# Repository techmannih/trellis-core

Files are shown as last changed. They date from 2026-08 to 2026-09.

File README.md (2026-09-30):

# Trellis Core

A compact, four-layer Linux board built around the Allwinner T113-S3 application processor.

## Overview

Trellis Core combines the processor, managed flash, power supplies, clocks, USB-C interface, boot controls, display expansion, debug UART, and a programmable status LED required for a small Linux-capable system. The complete schematic, component placement, connectivity, and autorouter configuration are written in TypeScript and JSX, making the board easy to inspect and modify as code.

## Hardware

| Block | Implementation |
| --- | --- |
| Processor | Allwinner T113-S3 application processor |
| Power input | 5 V through USB-C with resettable-fuse protection |
| Main rails | 3.3 V system rail and sequenced 0.9 V core rail |
| Auxiliary rails | 1.8 V and 1.5 V generated by the processor's internal regulators |
| Storage | ZDSD04GLGEAG 4 Gbit (512 MB) SD NAND on the four-bit SDC0 interface |
| USB | USB 2.0 data with ESD protection and USB-C configuration resistors |
| Clocks | 24 MHz main crystal and 32.768 kHz low-frequency crystal |
| Display expansion | SPI1 on a six-pin, 1 mm-pitch JST-SH connector |
| Debug | UART0 on a four-pin, 1 mm-pitch JST-SH connector |
| Status | 5 V XL-2121 addressable RGB LED driven through a 3.3 V-to-5 V AHCT buffer |
| Controls | Processor reset, boot selection, board identification, and flash clock control |
| PCB | 50 mm × 50 mm, four layers with an inner GND plane, 1.6 mm thick, four 2.7 mm mounting holes |
| Assembly | All components on the top side |
| Routing | Four-layer autorouting with `5x` effort, 0.15 mm minimum / 0.2 mm nominal traces, and 0.3 mm via holes with 0.45 mm pads |

## How it works

```mermaid
flowchart LR
  USB[USB-C connector] -->|5 V| FUSE[Resettable fuse]
  FUSE --> VBUS[Protected VBUS]
  VBUS --> BUCK33[3.3 V buck regulator]
  VBUS --> BUCK09[0.9 V buck regulator]
  BUCK33 -->|3.3 V| CPU[T113-S3 processor]
  BUCK33 -->|3.3 V| FLASH[Managed flash]
  BUCK33 -->|Power-good enables| BUCK09
  BUCK09 -->|0.9 V core| CPU
  USB <-->|D+ / D- through ESD protection| CPU
  CPU <-->|SDC0 data and command| FLASH
  CPU -->|SPI1| DISPLAY[6-pin JST-SH display connector]
  CPU <-->|UART0| DEBUG[4-pin JST-SH debug connector]
  CPU --> RGB[Addressable RGB status LED]
  CLOCKS[24 MHz and 32.768 kHz clocks] --> CPU
  CONTROLS[Reset and boot controls] --> CPU
  CONTROLS --> GATE[Flash clock gate]
  CPU --> GATE --> FLASH
```

1. The USB-C connector supplies 5 V power and USB 2.0 data. A resettable fuse protects the power path, while an ESD protection device sits between the connector and the processor's USB pins.
2. The first buck regulator creates the 3.3 V system rail. Its power-good output enables the second regulator so the 0.9 V processor core rail starts in sequence.
3. The processor uses its internal regulators for the 1.8 V and 1.5 V auxiliary rails. Local capacitors provide decoupling for every power domain.
4. The 24 MHz crystal provides the main clock and the 32.768 kHz crystal provides the low-frequency clock used by the processor.
5. Managed flash connects to the processor over the four-bit SDC0 bus. A logic gate, pull-ups, and a pushbutton network control the storage clock during boot and recovery.
6. SPI1 is broken out for a display, UART0 is available for a 3.3 V serial console, and the LEDC-capable PE5 pin drives the addressable RGB LED through U8 (SN74AHCT1G125) and a 33 Ω series resistor. U8 and the LED use protected VBUS; R27 holds the buffer input low during reset.
7. Reset, boot-selection, and board-identification resistor networks define the startup state. After placement, tscircuit autoroutes the board across all four copper layers.

## Expansion connectors

Both expansion connectors are JST-SH, 1 mm pitch. Pin numbering below follows the schematic and footprint definitions.

| J2 pin | SPI1 display signal | T113-S3 pin |
| --- | --- | --- |
| 1 | P3V3 | — |
| 2 | GND | — |
| 3 | SPI1_CLK | PD11 |
| 4 | SPI1_MOSI | PD12 |
| 5 | SPI1_MISO | PD13 |
| 6 | SPI1_CS0 | PD10 |

| J3 pin | UART0 debug signal | T113-S3 pin |
| --- | --- | --- |
| 1 | P3V3 | — |
| 2 | GND | — |
| 3 | UART0_TX | PE2 |
| 4 | UART0_RX | PE3 |

J3 uses 3.3 V logic. Use a 3.3 V USB-to-UART adapter, connect adapter RX to J3 TX and adapter TX to J3 RX, and do not apply 5 V to any J3 signal or power pin.

## How to program the board

Before applying power, follow [first-board power and firmware checks](docs/bring-up.md).
J1 is a 5 V input with passive CC pull-downs; it has no USB-PD negotiation or
source-current detection. Startup/steady current and USB source compatibility
must be measured on the prototype.

The board is programmed through its existing USB-C data connector using the T113-S3 BootROM's USB FEL mode. No separate programmer IC is fitted or required for this flow. SW2 disables the managed-flash clock so the installed image can be bypassed during recovery, and SW1 resets the processor. The boot behavior and peripheral pin functions are documented in the [T113-S3 user manual](https://turl.linux-sunxi.org/T113-S3/T113-S3_User_manual_v1.1_20210830.pdf) and [datasheet](https://dl.linux-sunxi.org/T113-S3/T113-S3_Datasheet_v1.6_20220303.pdf).

### Programming theory

Every time the processor is reset, it starts by executing an immutable first-stage program from its internal BootROM. Under normal conditions, the `SD_FLASH_CLK_GATE_EN` pull-up enables U6, allowing the SDC0 clock to reach the managed flash so the BootROM can load the installed boot image.

R12/R13 pull BOOT_SEL1/0 high. In GPIO boot-select mode, `11` tries SMHC0 first (T113-S3 user manual, Table 3-7), matching the SD NAND connection. This assumes the CPU has not been configured for an overriding eFuse boot policy.

Holding SW2 pulls `SD_FLASH_CLK_GATE_EN` low. U6 then blocks the storage clock, preventing the managed flash from responding during the next boot. After SW1 resets the processor, the BootROM cannot boot the stored image and exposes its FEL recovery interface over the USB data lines connected to J1. The host-side XFEL tool communicates directly with this BootROM interface, which is why an additional programmer IC is unnecessary.

FEL initially provides only a small recovery environment. XFEL first loads the T113-S3 DDR initialization code and can then upload a temporary loader, recovery U-Boot, or flashing image into RAM. That temporary program writes the final bootloader and system image to managed flash. Release SW2 once FEL is detected, before the RAM loader accesses storage. This restores the storage clock without resetting the CPU; resetting after a successful write starts the newly programmed image. J3 UART0 is optional and is used for boot logs and debugging, not for transferring the firmware image.

### Programming procedure

Identify the buttons by their component references:

| Button | Function | When to use it |
| --- | --- | --- |
| **SW1 — RESET** | Resets the T113-S3 processor | Press and release while holding SW2 to start recovery, or after programming to reboot. |
| **SW2 — FEL / SD FLASH DISABLE** | Blocks the SD NAND clock while held | Hold during power-on/reset to bypass storage boot; release after FEL detection, before accessing storage. |

1. Optionally connect J3 GND/TX/RX to a 3.3 V USB-to-UART adapter. Leave the adapter's power pin disconnected when USB-C powers the board.
2. Hold **SW2 (FEL)**, connect a USB-C **data** cable to the host, then press and release **SW1 (RESET)** while continuing to hold SW2. This powers and resets the CPU with the SD NAND clock blocked.
3. Run `xfel version` and confirm FEL detection. **Release SW2 (FEL) now**, without resetting, so a RAM loader can access the SD NAND.
4. Run `xfel ddr t113-s3`, then load a T113-S3 recovery image that supports this board's SDC0 pinout and SD NAND. No tested recovery image or partition layout is included in this repository.
5. Use that image's SD/MMC storage-writing procedure, verify the write, and reset with **SW1 (RESET)**. XFEL's `spinand` commands target SPI NAND and do not program this SDC0-attached part.

This is the intended hardware recovery path, verified against the netlist and component documentation. FEL entry, DDR initialization, and storage writes still need testing on a physical board with a compatible recovery image.

See the [XFEL quick start](https://xfel.xboot.org/en/guide/getting-started/) for host setup and RAM-loading examples; its [T113 implementation](https://github.com/xboot/xfel/blob/master/chips/r528_t113.c) provides the `t113-s3` DDR profile. Storage write offsets are image-specific and should not be guessed.

## RGB control

U7 is powered by protected 5 V VBUS. Its [manufacturer datasheet](https://www.lcsc.com/datasheet/C5349957.pdf) specifies full operation at 4.5–5.5 V and a DIN high threshold of 0.65 × VDD. U8's [TTL-compatible input](https://www.ti.com/lit/ds/symlink/sn74ahct1g125.pdf) accepts the CPU's 3.3 V output and drives DIN at the LED supply voltage. C45 and C46 bypass the LED and buffer separately. Configure PE5 for LEDC-DO and use the LED's single-wire protocol; WLED firmware is not included.

## Fabrication and assembly

Use [fabrication and assembly notes](docs/assembly.md) with the BOM and placement
files. D1 has a printed cathode `K` and anode/cathode fabrication labels. U5 and
U7 have 0.18 mm-stroke pin-1 circles and fabrication callouts. U5 retains its
1.27 mm solder-land spacing; the notes document coverage of the Zetta package's
1.25 mm-pitch terminals and the nominal 0.1575 mm minimum side margin.
The board uses 0.30 mm via holes and 0.45 mm
outer copper diameters; select the corresponding fabrication option.

`bun run check:assembly` checks U5 terminal coverage, the presence of polarity
notes, and the position, stroke and pad clearance of the pin-1 markers. It is
part of `bun run verify`. After verification, `bun run export:assembly` creates
`dist/index/assembly-top.svg`, showing pads, pin numbers, silk and fabrication
notes without routed copper. Send that drawing and `docs/assembly.md` to the
assembler and inspect the actual placement preview before manufacturing.

## Decoupling and review checks

The board selects `autorouterVersion="beta_pipeline7"` to preserve its explicit bypass, crystal, and LED signal paths as fixed copper. With the pinned tscircuit version, Pipeline 9 can move these paths and introduce vias despite `maxViaCount={0}`. Via-to-pad clearance is explicitly set to 0.1 mm so routing and final DRC use the same limit. The Y1–C33 load-capacitor branch also has an explicit zero-via route.

The 0.45 mm via pads are used throughout, including the manual ground vias. Routing uses a 0.15 mm minimum trace width; the C21 and LXIN escape corners are staggered to maintain clearance at that width.

No dependency patch is applied. `scripts/via-net-identity.test.mjs` uses the real autorouter to route GND and SIGNAL on inner1, then checks that each copper route reaches both intended through-vias and stays separate from the other net. The vias themselves must remain connected to their declared source nets. It does not require a particular source trace ID or replace the board's copper-short check. The missing route-attribution case is reproduced in [core #4002](https://github.com/tscircuit/core/pull/4002), and the same-GND short reports are covered by [check-shorts #62](https://github.com/tscircuit/check-shorts/pull/62) and addressed upstream by [fix #65](https://github.com/tscircuit/check-shorts/pull/65).

The [decoupling map](scripts/decoupling-map.json) lists every local bypass capacitor, its exact IC power/reference pin, and its maximum routed length. Each `DECOUPLE_C*` trace has a dedicated physical path. All components are assembled on the top side. Every bypass path stays on top with no vias and a 3 mm ceiling; adjacent CPU power pins fan out to spaced capacitor rows around the package. Capacitor pin 1 faces the IC. Each pin 2 has a dedicated return of at most 1 mm to a nearby through-via tied to the inner GND plane. `decouplingFor` remains on each capacitor for inspection; an explicit trace supplies the physical route, so `decouplingTo` is intentionally omitted to avoid duplicate generated traces.

`bun run check:decoupling` measures the built copper polyline, including both sides of vias and via depth. It fails for missing/wrong pin mappings, missing direct routes, ungrounded capacitors, changed limits, excessive length, bottom-side components, bypass layer changes, or any build errors. It is part of `bun run verify`. These are board layout constraints, not a substitute for power-integrity measurements.

The remaining capacitors have different roles: C3/C5/C6 are regulator output reservoirs; C10/C22/C29 are rail bulk storage; C2/C4 are feedback feed-forward capacitors; C8 is the power-good filter; C32/C33/C36/C37 are crystal loads; C40 is the reset filter; C44 filters the flash-clock enable. They are not counted as local IC bypasses.

The schematic uses power-marked rails, a standard USB-C connector symbol, and crystal symbols for Y1/Y2. Signal nets with voltage text in their names are explicitly classified to keep their labels correct. Net labels and power/ground symbols are generated automatically; this project does not use manual `<netlabel>` elements. The expansion sheet groups the populated SPI/UART connectors, boot straps, and RGB circuitry; CPU power and bypasses remain together on CPU Core.

## Uses

- A starting point for compact Linux-based controllers and USB-connected embedded devices
- A reference design for T113-S3 power sequencing, clocking, storage, and USB integration
- An example of describing a dense processor board entirely in tscircuit and TypeScript
- A test project for PCB placement, autorouting, 3D rendering, and manufacturing-export workflows
- A base design with SPI display and UART debug expansion for application-specific firmware

The current board focuses on the processor core, power, USB, storage, a compact SPI display bus, and serial debug. Additional product-specific I/O may still be needed before using it as a complete end product.

## Getting started

Install [Bun](https://bun.sh/), then run:

```sh
bun install
bun run dev
```

`bun run dev` opens the interactive tscircuit viewer, where the schematic, PCB, and 3D assembly can be inspected.

## Commands

| Command | Purpose |
| --- | --- |
| `bun run dev` | Open the interactive tscircuit viewer |
| `bun run typecheck` | Check the TypeScript source |
| `bun run verify` | Run netlist, placement, build, actual decoupling length, and copper-short checks |
| `bun run check:decoupling` | Check local bypass routes in the existing build |
| `bun run check:assembly` | Check flash terminal coverage, polarity notes and orientation markers |
| `bun run export:assembly` | Generate the top-side assembly drawing from the verified build |
| `bun run build` | Generate circuit JSON under `dist/` |
| `bun run build:preview` | Generate PCB, schematic, and 3D preview images |
| `bun run build:handoff` | Generate KiCad, STEP, and GLB handoff files |
| `bun run snapshot:update` | Refresh checked PCB and schematic snapshots |
| `bun run snapshot:3d:update` | Refresh the checked 3D snapshot |

## Generated outputs

Build artifacts are written under `dist/`:

- `dist/index/circuit.json` contains the complete generated circuit
- Preview builds add PCB, schematic, and 3D images
- Handoff builds add a KiCad project archive, STEP model, and GLB models

## Project structure

```text
.
├── index.circuit.tsx      Board definition, connectivity, and placement
├── imports/               Component wrappers, footprints, and CAD models
├── __snapshots__/         Checked PCB, schematic, and 3D renders
├── tscircuit.config.json  Project entrypoint and build configuration
├── tsconfig.json          TypeScript configuration
└── package.json           Development, verification, and export commands
```

## Current status

Run `bun run verify` to reproduce the electrical, placement, routed decoupling, and copper-short checks. Checked schematic, PCB, and 3D views are stored in `__snapshots__/`.

Hardware bring-up and a compatible recovery/flashing image remain unverified.
Use [the bring-up procedure and results record](docs/bring-up.md) to capture
current/rail measurements, FEL, DDR, storage and boot evidence. Inspect the
generated handoff files and run fabrication-specific DRC before manufacturing.

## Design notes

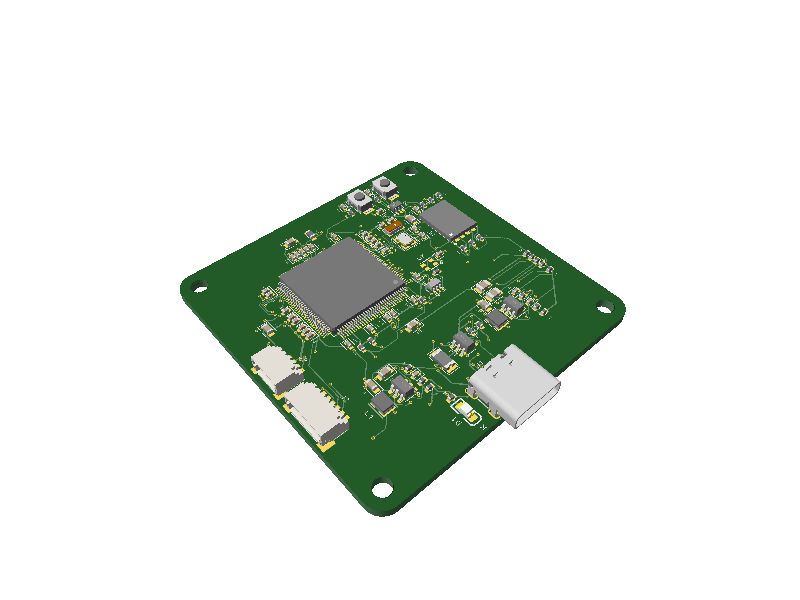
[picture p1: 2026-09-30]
__snapshots__/index.circuit-3d.snap.png

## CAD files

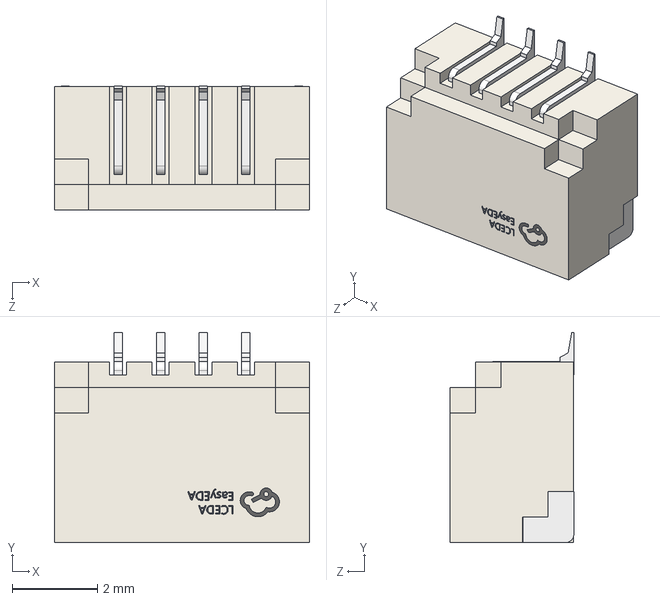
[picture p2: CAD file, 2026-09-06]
imports/SM04B_SRSS_TB_LF__SN_/SM04B_SRSS_TB_LF__SN_.step
6.00 x 4.95 x 2.91 mm

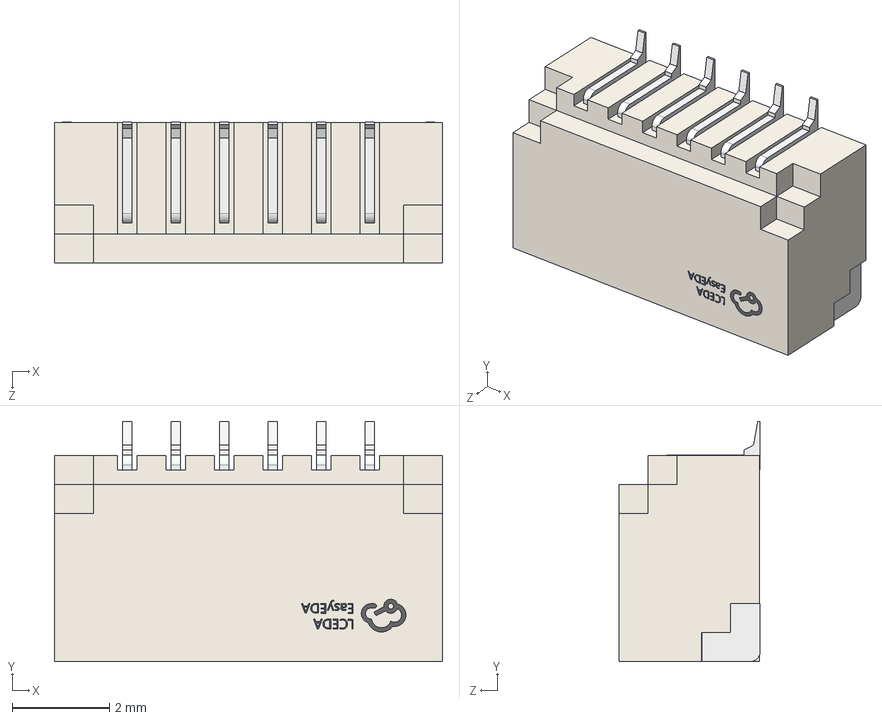
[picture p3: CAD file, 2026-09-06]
imports/SM06B_SRSS_TB_LF__SN_/SM06B_SRSS_TB_LF__SN_.step
8.00 x 4.95 x 2.91 mm

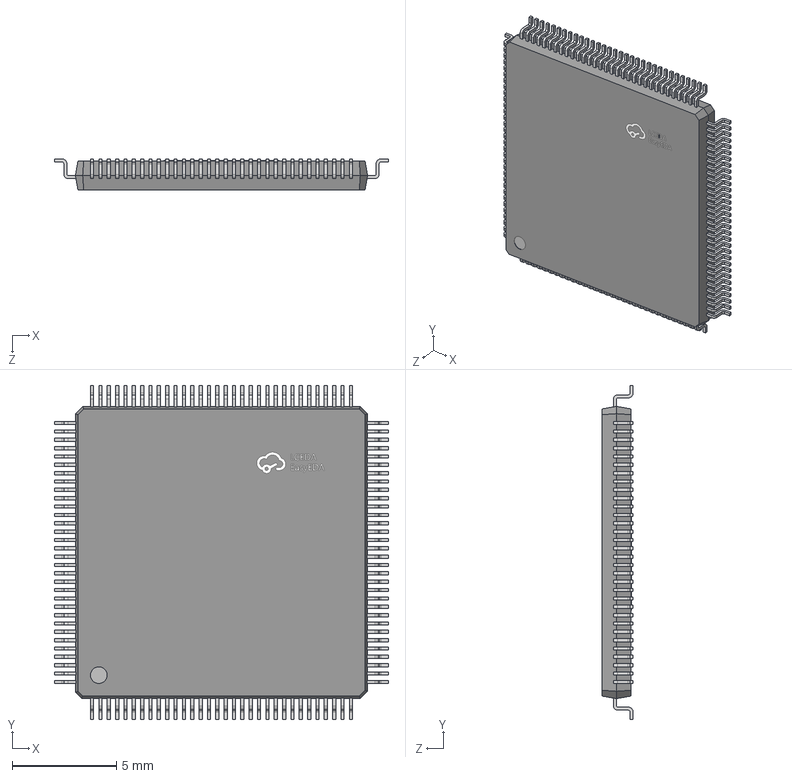
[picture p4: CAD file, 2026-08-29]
imports/T113_S3/T113_S3.step
16.0 x 16.0 x 1.50 mm

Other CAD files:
imports/SM04B_SRSS_TB_LF__SN_/SM04B_SRSS_TB_LF__SN_.obj
imports/SM06B_SRSS_TB_LF__SN_/SM06B_SRSS_TB_LF__SN_.obj
imports/T113_S3/T113_S3.obj

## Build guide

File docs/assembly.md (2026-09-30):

# Fabrication and assembly notes

Applies to the Trellis Core layout in this repository. View the board from the
component/top side with USB-C J1 at the bottom. All components are top-side.

## Files to supply with the order

Run `bun run verify`, then `bun run export:assembly`. Supply the resulting
`dist/index/assembly-top.svg` and this document with the BOM, component placement
file and final fabrication outputs. The assembly drawing is a top view, not a
mirrored bottom view. Fabrication notes belong in the assembly/F.Fab documentation;
they are not extra copper or extra silkscreen text.

Confirm that the assembler's placement preview aligns the physical package marks
with the pad functions below. A placement-file rotation number alone is
insufficient because library zero-angle conventions can differ.

## Orientation of the polarized parts

| Reference | Part | Orientation on this board |
| --- | --- | --- |
| D1 | NCD0805R1 | Pin 2/anode is the upper pad, connected to P3V3. Pin 1/cathode is the lower pad, connected through R4 to GND. The printed `K` identifies the cathode end; assembly labels are `A (+)` and `K (-)`. |
| U5 | ZDSD04GLGEAG | Pin 1/DAT2 is the leftmost pad in the lower row. Align the package pin-1 corner with the PCB circle and `1 DAT2` callout. U5 is placed at 90 degrees in the source layout. |
| U7 | XL-2121RGBC-2812B | The package's marked/chamfered corner is pin 1/DIN, at the lower-right corner on this board. Align it with the PCB circle and `1 DIN` callout. |

U7 top view:

```text
       3 / DO       2 / VDD (+5 V)
           +-------+
           |  U7   |
           +------/  <- package mark
       4 / GND      1 / DIN   o <- PCB dot
```

Pin 3/DO is intentionally unconnected. Do not use a generic WS2812 package pinout
to override the drawing for this exact XINGLIGHT part.

U5 top view in its current board rotation:

```text
   8 VDD     7 DAT1     6 DAT0     5 CMD
        +-----------------------+
        |          U5           |
        +-----------------------+
   1 DAT2    2 DAT3     3 CLK      4 GND
 o <- PCB pin-1 circle
```

### U5 package pitch and solder lands

The Zetta package has **1.25 mm terminal pitch**. The existing PCB solder lands
retain **1.27 mm spacing**, with centers at +/-1.905 and +/-0.635 mm in each
unrotated column. These are different dimensions: the wider solder lands can
accommodate the package terminals. With a centered package, the largest terminal
center offset is 0.030 mm. The 0.800 mm land width along the pitch direction and
datasheet maximum terminal width `b = 0.425 mm` leave a minimum nominal side
margin of `(0.800 - 0.425) / 2 - 0.030 = 0.1575 mm`.

This land pattern preserves the verified copper routing. The geometry check
requires at least 0.15 mm nominal side margin; it does not establish assembly
placement/process tolerances. Ask the assembler to confirm this exact LGA8 land
pattern against the package drawing during DFM. Do not substitute a generic
1.27 mm-pitch IC for U5.

U5 and U7 orientation circles use 0.18 mm strokes; D1's cathode character is
1 mm high.

The remaining ICs must also match their pin-1 marks and the placement preview.
J2/J3 pin 1 is P3V3 and pin 2 is GND; connector pinouts are in the README. All
populated capacitors are ceramic/MLCC parts and do not require +/- polarity.

## PCB fabrication settings

| Item | Design value |
| --- | --- |
| Size | 50 x 50 mm |
| Copper layers | 4; inner1 is GND |
| Nominal thickness | 1.6 mm |
| Via hole / outer copper diameter | 0.30 / 0.45 mm |
| Via radial annular ring | 0.075 mm |
| Trace width | 0.15 mm minimum; 0.20 mm nominal |
| Mounting holes | Four 2.7 mm NPTH holes |

Select the **0.30 mm minimum via-hole option**. Do not allow the drill size to be
enlarged automatically without checking the copper ring and all clearances.
Confirm support and pricing for 0.30/0.45 mm vias in the fabrication quote.
If changing outer diameters for cost, rerun routing
and clearance checks. The chosen copper weight, stackup, mask treatment and
surface finish must be reflected in the actual manufacturing order.

Before release, inspect the generated Gerber/drill files and placement preview,
including pin-1 marks, mask openings and the manufacturer's DFM results. The
repository's checks do not replace that review.

## Reference drawings

- [Zetta ZDSD04GLGEAG manufacturer datasheet](https://www.lcsc.com/datasheet/C2875854.pdf): revision 1.3, printed pages 4 and 16, top-view pin assignment and LGA8 dimensions (`e = 1.25 BSC`).
- [XINGLIGHT XL-2121RGBC-2812B manufacturer datasheet](https://www.lcsc.com/datasheet/C5349957.pdf): printed page 11, marked corner, top-view DI/VDD/DO/GND arrangement and pin table.
- [JLCPCB rigid PCB capabilities](https://jlcpcb.com/capabilities/pcb-capabilities): via/drill and legend dimensions, checked 15 September 2026. Recheck the selected process at order time.

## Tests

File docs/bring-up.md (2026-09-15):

# First-board power and firmware test

Status: **not yet tested on physical hardware**. This procedure makes the open
checks reproducible; it is not a record of a successful boot.

## Power-input contract

J1 accepts **5 V**. Its CC1 and CC2 each have a 5.1 kohm pull-down. The board has
no USB-PD controller or CC current-advertisement detector. It therefore does not
negotiate a higher voltage or determine whether a Type-C source advertises
1.5 A/3 A. Do not assume either current is available from every USB port.

For bench evaluation, use a known regulated 5 V source with at least 1 A capacity
and adjustable current limiting, through a suitable USB power fixture. Source
capacity is test headroom, not measured board demand or permission to exceed a
USB port's advertised allowance. F1 is a resettable fuse, not a USB current
negotiator or precise current limiter. Record startup peaks as well as steady
current, including any load on J2/J3.

For FEL/data tests, choose a host/hub or powered test fixture that supports both
USB data and the measured demand. If using separate bench power while connected
to a host, use a fixture that isolates the host's VBUS; do not directly parallel
two 5 V sources. When J1 powers the board, leave the UART adapter's power pin
disconnected and connect only GND/TX/RX at 3.3 V logic levels.

If measured demand exceeds the applicable default USB allowance, resolve the
power architecture before qualifying general USB operation: reduce demand or
add appropriate source-current detection/current control. Add PD negotiation if
the intended product requires a PD contract. An arbitrary larger supply does not
close this compatibility check.

## Test order

1. **Unpowered inspection:** compare D1/U5/U7 marks against [assembly.md](assembly.md),
   inspect solder joints and check for sustained low-resistance shorts between
   VBUS/power rails and GND. Allow capacitors to charge during resistance checks.
2. **Initial power:** with RESET held, apply 5.0 V with a conservative initial
   current limit (for example 100 mA for a short-check stage). Record whether the
   supply limits. This low-limit stage is not a boot test; investigate a sustained
   limit before increasing it. Stop and inspect if a component heats unexpectedly.
3. **Rail checks:** measure protected VBUS and nominal 3.3 V, 0.9 V, 1.8 V and
   1.5 V at accessible capacitor pads. Record results; compare measured limits to
   the regulator/processor datasheets. Use a scope to confirm that 3.3 V precedes
   the 0.9 V rail and to inspect startup/reset behavior. Check the drop across F1.
4. **Startup current:** establish a justified current limit within the source,
   connector and board limits, release RESET and record peak and steady current.
   A current-limited brownout is not evidence by itself of a bad PCB.
5. **FEL:** follow the README's SW2/SW1 sequence using a USB data connection.
   Record `xfel version` output. Release SW2 after FEL detection before accessing
   the SD NAND clocked through U6.
6. **DDR and storage:** record `xfel ddr t113-s3` output. Use a compatible RAM
   recovery image with this board's SDC0 pinout and managed SD NAND support.
   Record the exact image revision/checksum and its partition/write procedure.
   Do not substitute XFEL's SPI-NAND write commands for this SD/MMC device.
7. **Boot verification:** verify the storage write/readback, reset, collect UART
   logs, and repeat a cold boot. Then check the RGB LED and any expansion load,
   repeating the current measurement under that load.

No tested recovery image or partition layout is shipped here. Storage write
offsets are image-specific; physical testing and a compatible image are needed
to close the firmware item.

## Results record

Copy this table for each board. Replace `NOT TESTED` only with measured evidence.

| Check | Result / evidence |
| --- | --- |
| Board ID, PCB revision and source commit | NOT TESTED |
| Assembly orientation and unpowered short check | NOT TESTED |
| Supply/fixture, current limit, cable and source current allowance | NOT TESTED |
| Protected VBUS; F1 voltage drop | NOT TESTED |
| 3.3 V / 0.9 V / 1.8 V / 1.5 V measurements | NOT TESTED |
| 3.3 V to 0.9 V sequencing waveform | NOT TESTED |
| Startup peak / steady current; attached expansion load | NOT TESTED |
| FEL identification output | NOT TESTED |
| DDR initialization output | NOT TESTED |
| Recovery image checksum and partition/write procedure | NOT TESTED |
| Storage readback verification | NOT TESTED |
| UART boot log / repeated cold boots | NOT TESTED |
| RGB and expansion functionality; loaded current | NOT TESTED |

References: [USB Type-C specification, Release 2.4](https://e2e.ti.com/cfs-file/__key/communityserver-discussions-components-files/196/USB-Type_2D00_C-Spec-R2.4-_2D00_-October-2024.pdf),
[T113-S3 datasheet](https://dl.linux-sunxi.org/T113-S3/T113-S3_Datasheet_v1.6_20220303.pdf),
and the README's linked component and XFEL documentation.
